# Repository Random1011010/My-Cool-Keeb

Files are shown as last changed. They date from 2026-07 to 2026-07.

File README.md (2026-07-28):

# My-Cool-Keeb
# Name: Morning Star

**Morning Star** is a custom 81-key mechanical keyboard powered by the **Hack Club Orpheus Pico** (RP2040). Built with dual rotary encoders, ultra-quiet linear switches, and a custom 2-layer PCB inside a 3D-printed enclosure, it delivers a high-functionality, low-noise typing experience.

Screenshot 2026-07-28 at 3 13 28 PM

---

## 🛠️ Project Writeup

### What I Built
Morning Star is a custom-designed, 81-key mechanical keyboard featuring a dedicated function row, arrow cluster, and dual EC11 rotary encoders. 

* **Microcontroller**: Powered by the Hack Club Orpheus Pico (RP2040).
* **Sound Profile**: Engineered for silent operation using Outemu Silent White linear switches, blank MOA profile PBT keycaps, and pre-clipped Chosfox V3 plate-mount stabilizers.
* **PCB & Hardware**: Custom 2-layer PCB designed, housed in a 3D-printed enclosure held together with M3 brass heat-set inserts and stainless steel hex socket screws.

---

### Why I Built It
Standard off-the-shelf mechanical keyboards are often either too noisy for shared environments or lack the physical control density needed for media editing, live sound workflows, and rapid navigation. 

I wanted to design a custom board from scratch that solved these problems:
1. **Dual Encoder Control**: Placing two tactile knobs directly on the layout gives instant physical control over volume, timeline scrubbing, and macro adjustments without leaving the home row.
2. **Silent Treatment**: By choosing silent white linear switches and plate-mounted stabilizers with pre-clipped stems, I wanted to eliminate rattle and any noise (I study at night so I would get in trouble if it was loud).

---

### What I Learned
Building Morning Star involved learning hardware production, PCB fabrication constraints, and firmware matrix logic:

* **PCB Manufacturing & Cost Optimization**: I learned how small design decisions directly impact manufacturing price. By selecting "Tented" via covering, I eliminated extra processing surcharges on JLCPCB while keeping standard matrix routing intact.
* **Hardware Sourcing & Budgeting**: Balancing component lead times and shipping fees taught me how to structure a realistic Bill of Materials across multiple suppliers (AliExpress, Amazon, JLCPCB) while staying strictly within budget limits.
* **Mechanical Design & Fasteners**: I learned why direct-threading screws into 3D-printed plastic leads to stripped threads over time, and how using a soldering iron to melt brass heat-set inserts into internal bosses provides strong, long-lasting metal threads for continuous teardowns.
* **Matrix Logic & Firmware**: I gained experience configuring diode-isolated key matrices (1N4148 diodes) to ensure full N-Key Rollover (NKRO) without ghosting, as well as mapping quadrature encoder signals to GPIO pins on the RP2040.

---

## 📋 Bill of Materials (BOM)

| Part Description | Qty | Unit Cost (USD) | Total Cost (USD) | Source / Link |
| :--- | :---: | :---: | :---: | :--- |
| **Orpheus Pico Microcontroller** | 1 | $0.00 | $0.00 | [Hack Club GitHub](https://github.com/hackclub/orpheus-pico) |
| **Outemu Silent White Linear Switches** (90 pcs) | 90 | $0.27 | $23.90 | [AliExpress](https://www.aliexpress.com/item/1005002378701948.html) |
| **132-Key White Blank MOA Profile Keycaps** | 1 | $20.96 | $20.96 | [AliExpress](https://www.aliexpress.com/) |
| **1N4148 Signal Diodes** (100-pack) | 100 | $0.016 | $1.64 | [AliExpress](https://www.aliexpress.com/item/1005002339916163.html) |
| **EC11 20mm Rotary Encoders** (2-pack) | 1 | $3.50 | $3.50 | [AliExpress](https://www.aliexpress.com/) |
| **M3 x 20mm Stainless Steel Screws** (100-pack) | 100 | $0.052 | $5.22 | [AliExpress](https://www.aliexpress.com/) |
| **HANGLIFE M3 Brass Heat-Set Inserts** (100-pack) | 100 | $0.057 | $5.66 | [Amazon Canada](https://www.amazon.ca/) |
| **Chosfox V3 Plate Mount Stabilizers Kit** | 1 | $8.57 | $8.57 | [AliExpress](https://www.aliexpress.com/item/1005007299976098.html) |
| **Custom 2-Layer PCB Fabrication** (5 pcs total) | 1 | $58.85 | $58.85 | [JLCPCB](https://jlcpcb.com/) |
| **Total Estimated Cost** | | | **~$128.30 USD** | |

---

## 🛠️ Hardware Specifications

* **MCU**: Hack Club Orpheus Pico (RP2040)
* **Matrix Architecture**
* **Encoders**: 2x EC11 5-pin encoders connected to dedicated GPIO channels.
* **Enclosure Fasteners**: M3 x D5 x L4 mm brass heat-set inserts with M3 x 20mm.
* **Stabilizers**: Chosfox V3 plate-mount stabilizers for keycaps ≥ 2u.

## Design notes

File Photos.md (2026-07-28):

### Photos ###
Screenshot 2026-07-15 at 4 56 42 PM








Screenshot 2026-07-28 at 3 13 28 PM

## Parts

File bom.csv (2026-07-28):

Item | Description | Quantity | Unit Price (USD) | Total Price (USD) | Purchase Link
Orpheus Pico Microcontroller | Hack Club RP2040 Board (Orpheus Pico) | 1 | 0.00 | 0.00 | https://github.com/hackclub/orpheus-pico
Mechanical Switches | Outemu Silent White Linear Switches (90 pcs) | 90 | 0.27 | 23.90 | https://www.aliexpress.com/item/1005002378701948.html
Keycap Set | 132 Keys White Blank MOA Profile PBT Keycaps | 1 | 20.96 | 20.96 | https://www.aliexpress.com/item/1005009872636789.html?mp=1
1N4148 Diodes | 100pcs 1N4148 In-line Switching Diodes | 100 | 0.016 | 1.64 | https://www.aliexpress.com/item/1005002339916163.html
EC11 Rotary Encoders | EC11 20mm D-Shaft Rotary Encoder | 2 | 1.75 | 3.50 | https://www.aliexpress.com/item/1005008790852587.html?mp=1
PCB Mount Stabilizers | 2x Stabilizers (1x Spacebar 6.25u / 1x Left Shift 2u) | 2 | 1.82 | 3.65 | https://www.aliexpress.com/item/1005007299976098.html
M3 screws | M3 x 20mm Machine Screws | 1 | 5.22 | 5.22 | https://www.aliexpress.com/item/32794842281.html?mp=1
Heat-Set Inserts | HANGLIFE 100pcs M3 x D5 x L4 Brass Heat-Set Threaded Inserts | 100 | 0.057 | 5.66 | https://www.amazon.ca/gp/product/B0CS6VZYL8/ref=ewc_pr_img_1?smid=A2SU9MLZ0N1BK2&th=1
Custom PCB Fabrication | JLCPCB 2-Layer Custom PCB (5 pcs incl. shipping & duties) | 1 | 58.85 | 58.85 | https://jlcpcb.com/
TOTAL |  |  |  |  | $128.30

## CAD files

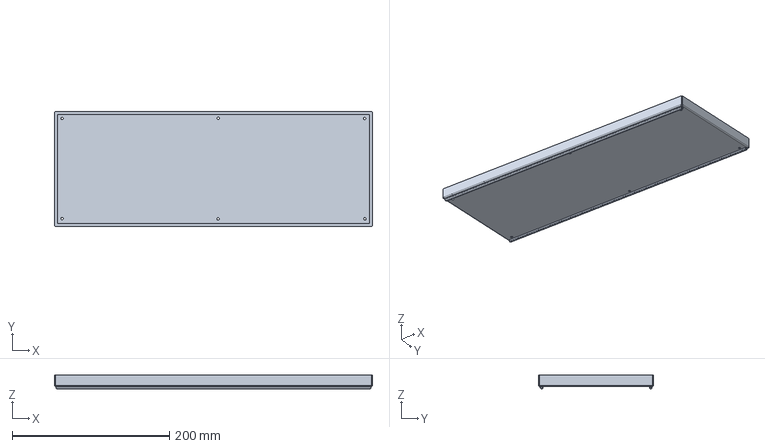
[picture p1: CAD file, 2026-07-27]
Case Files/Bottom Plate.step
404.1 x 145.9 x 17.5 mm

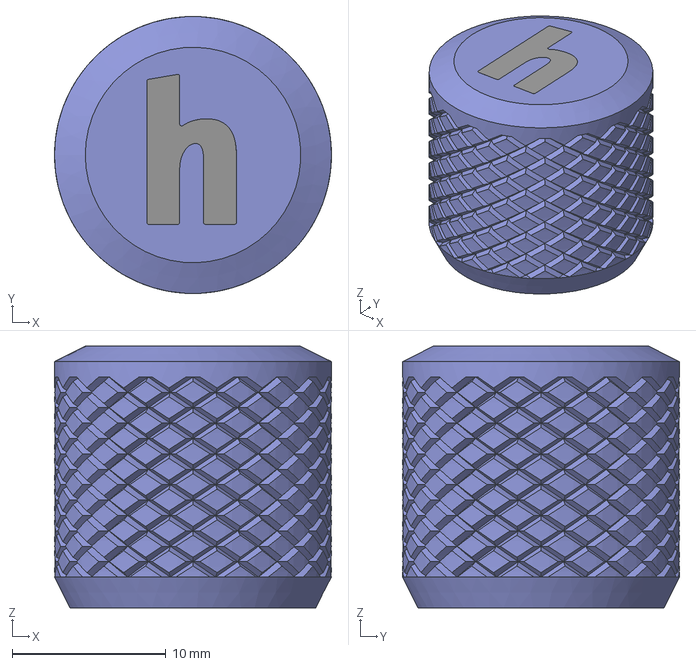
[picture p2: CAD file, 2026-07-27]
Case Files/Knob 1.step
18.0 x 18.0 x 17.0 mm

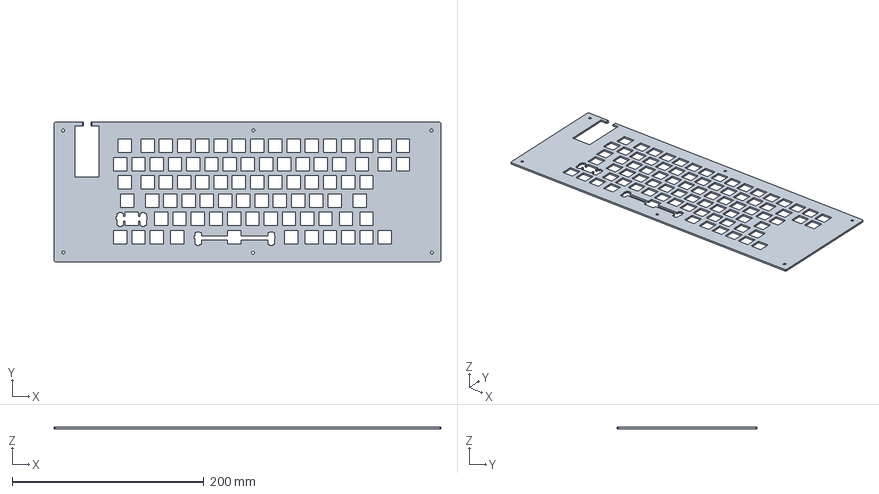
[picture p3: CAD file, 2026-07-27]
Case Files/Mid Plate.step
404.1 x 145.9 x 2.00 mm

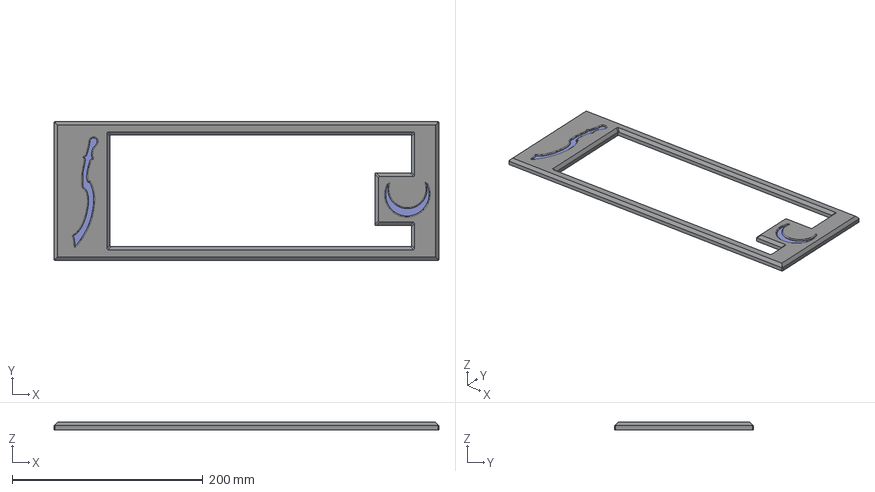
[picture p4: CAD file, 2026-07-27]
Case Files/Top Plate.step
404.1 x 145.9 x 8.00 mm

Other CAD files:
Case Files/Knob 2.step

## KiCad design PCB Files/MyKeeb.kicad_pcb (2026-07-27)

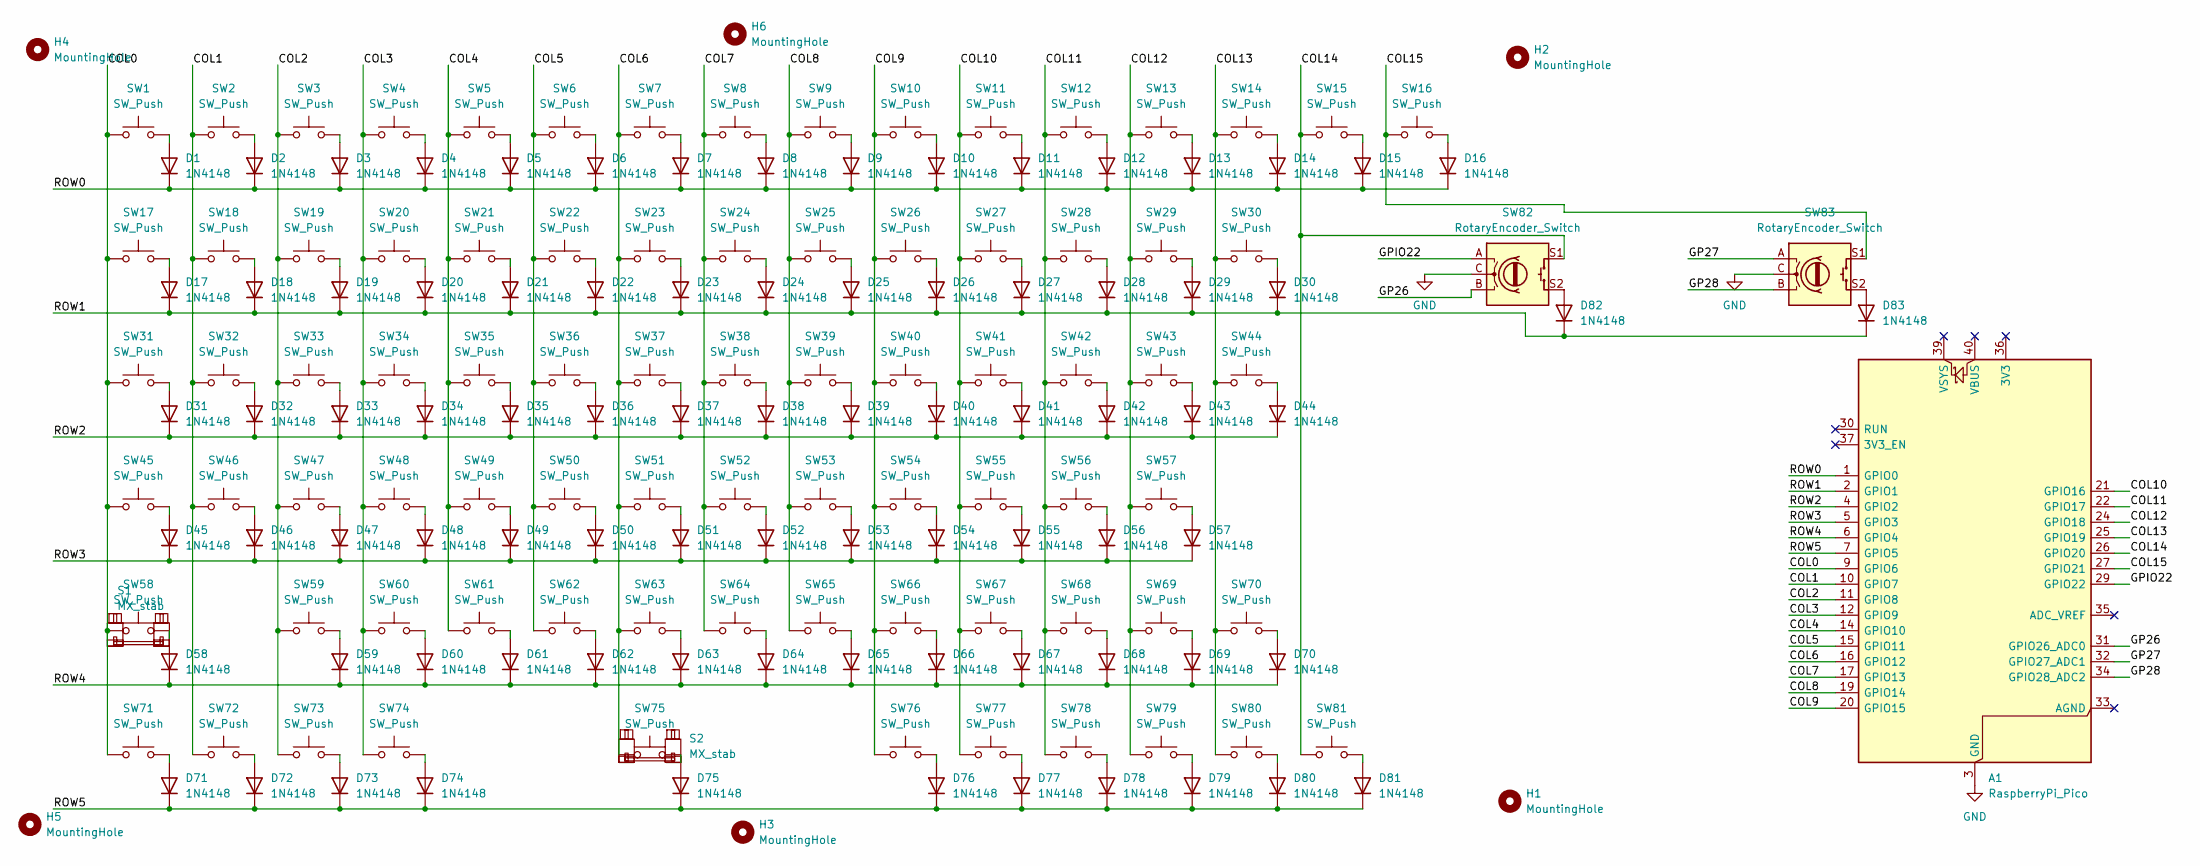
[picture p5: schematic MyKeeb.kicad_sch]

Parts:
A1: RaspberryPi_Pico; RaspberryPi_Pico_Common_THT
D1, D2, D3, D4, D5, D6, D7, D8, D9, D10, D11, D12, D13, D14, D15, D16, D17, D18, D19, D20, D21, D22, D23, D24, D25, D26, D27, D28, D29, D30, D31, D32, D33, D34, D35, D36, D37, D38, D39, D40, D41, D42, D43, D44, D45, D46, D47, D48, D49, D50, D51, D52, D53, D54, D55, D56, D57, D58, D59, D60, D61, D62, D63, D64, D65, D66, D67, D68, D69, D70, D71, D72, D73, D74, D75, D76, D77, D78, D79, D80, D81, D82, D83: 1N4148; D_DO-35_SOD27_P7.62mm_Horizontal
H1, H2, H3, H4, H5, H6: MountingHole; MountingHole_3.2mm_M3
S1: MX_stab; STAB_MX_P_2.25u
S2: MX_stab; STAB_MX_P_5u
SW1, SW30, SW31: SW_Push; SW_MX_1.5u
SW2, SW3, SW4, SW5, SW6, SW7, SW8, SW9, SW10, SW11, SW12, SW13, SW14, SW15, SW16, SW17, SW18, SW19, SW20, SW21, SW22, SW23, SW24, SW25, SW26, SW27, SW28, SW29, SW32, SW33, SW34, SW35, SW36, SW37, SW38, SW39, SW40, SW41, SW42, SW43, SW44, SW46, SW47, SW48, SW49, SW50, SW51, SW52, SW53, SW54, SW55, SW56, SW58, SW59, SW60, SW61, SW62, SW63, SW64, SW65, SW66, SW67, SW68, SW70, SW71, SW72, SW73, SW75, SW77, SW78, SW79, SW80, SW81: SW_Push; SW_MX_1u
SW45, SW57: SW_Push; SW_MX_1.75u
SW69, SW74, SW76: SW_Push; SW_MX_1.25u
SW82, SW83: RotaryEncoder_Switch; ROT_Alps_EC11E-Switch

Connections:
/COL0: A1.9 (GPIO6), SW1.1, SW17.1, SW31.1, SW45.1, SW58.1, SW71.1
/COL1: A1.10 (GPIO7), SW2.1, SW18.1, SW32.1, SW46.1, SW72.1
/COL2: A1.11 (GPIO8), SW3.1, SW19.1, SW33.1, SW47.1, SW59.1, SW73.1
/COL3: A1.12 (GPIO9), SW4.1, SW20.1, SW34.1, SW48.1, SW60.1, SW74.1
/COL4: A1.14 (GPIO10), SW5.1, SW21.1, SW35.1, SW49.1, SW61.1
/COL5: A1.15 (GPIO11), SW6.1, SW22.1, SW36.1, SW50.1, SW62.1
/COL6: A1.16 (GPIO12), SW7.1, SW23.1, SW37.1, SW51.1, SW63.1, SW75.1
/COL7: A1.17 (GPIO13), SW8.1, SW24.1, SW38.1, SW52.1, SW64.1
/COL8: A1.19 (GPIO14), SW9.1, SW25.1, SW39.1, SW53.1, SW65.1
/COL9: A1.20 (GPIO15), SW10.1, SW26.1, SW40.1, SW54.1, SW66.1, SW76.1
/COL10: A1.21 (GPIO16), SW11.1, SW27.1, SW41.1, SW55.1, SW67.1, SW77.1
/COL11: A1.22 (GPIO17), SW12.1, SW28.1, SW42.1, SW56.1, SW68.1, SW78.1
/COL12: A1.24 (GPIO18), SW13.1, SW29.1, SW43.1, SW57.1, SW69.1, SW79.1
/COL13: A1.25 (GPIO19), SW14.1, SW30.1, SW44.1, SW70.1, SW80.1
/COL14: A1.26 (GPIO20), SW15.1, SW81.1, SW82.S1
/COL15: A1.27 (GPIO21), SW16.1, SW83.S1
/GP26: A1.31 (GPIO26_ADC0), SW82.B
/GP27: A1.32 (GPIO27_ADC1), SW83.A
/GP28: A1.34 (GPIO28_ADC2), SW83.B
/GPIO22: A1.29 (GPIO22), SW82.A
/ROW0: A1.1 (GPIO0), D1.1 (K), D2.1 (K), D3.1 (K), D4.1 (K), D5.1 (K), D6.1 (K), D7.1 (K), D8.1 (K), D9.1 (K), D10.1 (K), D11.1 (K), D12.1 (K), D13.1 (K), D14.1 (K), D15.1 (K), D16.1 (K)
/ROW1: A1.2 (GPIO1), D17.1 (K), D18.1 (K), D19.1 (K), D20.1 (K), D21.1 (K), D22.1 (K), D23.1 (K), D24.1 (K), D25.1 (K), D26.1 (K), D27.1 (K), D28.1 (K), D29.1 (K), D30.1 (K), D82.1 (K), D83.1 (K)
/ROW2: A1.4 (GPIO2), D31.1 (K), D32.1 (K), D33.1 (K), D34.1 (K), D35.1 (K), D36.1 (K), D37.1 (K), D38.1 (K), D39.1 (K), D40.1 (K), D41.1 (K), D42.1 (K), D43.1 (K), D44.1 (K)
/ROW3: A1.5 (GPIO3), D45.1 (K), D46.1 (K), D47.1 (K), D48.1 (K), D49.1 (K), D50.1 (K), D51.1 (K), D52.1 (K), D53.1 (K), D54.1 (K), D55.1 (K), D56.1 (K), D57.1 (K)
/ROW4: A1.6 (GPIO4), D58.1 (K), D59.1 (K), D60.1 (K), D61.1 (K), D62.1 (K), D63.1 (K), D64.1 (K), D65.1 (K), D66.1 (K), D67.1 (K), D68.1 (K), D69.1 (K), D70.1 (K)
/ROW5: A1.7 (GPIO5), D71.1 (K), D72.1 (K), D73.1 (K), D74.1 (K), D75.1 (K), D76.1 (K), D77.1 (K), D78.1 (K), D79.1 (K), D80.1 (K), D81.1 (K)
GND: A1.3 (GND), A1.8 (GND), A1.13 (GND), A1.18 (GND), A1.23 (GND), A1.28 (GND), A1.38 (GND), SW82.C, SW83.C
unnamed: D1.2 (A), SW1.2
unnamed: D2.2 (A), SW2.2
unnamed: D3.2 (A), SW3.2
unnamed: D4.2 (A), SW4.2
unnamed: D5.2 (A), SW5.2
unnamed: D6.2 (A), SW6.2
unnamed: D7.2 (A), SW7.2
unnamed: D8.2 (A), SW8.2
unnamed: D9.2 (A), SW9.2
unnamed: D10.2 (A), SW10.2
unnamed: D11.2 (A), SW11.2
unnamed: D12.2 (A), SW12.2
unnamed: D13.2 (A), SW13.2
unnamed: D14.2 (A), SW14.2
unnamed: D15.2 (A), SW15.2
unnamed: D16.2 (A), SW16.2
unnamed: D17.2 (A), SW17.2
unnamed: D18.2 (A), SW18.2
unnamed: D19.2 (A), SW19.2
unnamed: D20.2 (A), SW20.2
unnamed: D21.2 (A), SW21.2
unnamed: D22.2 (A), SW22.2
unnamed: D23.2 (A), SW23.2
unnamed: D24.2 (A), SW24.2
unnamed: D25.2 (A), SW25.2
unnamed: D26.2 (A), SW26.2
unnamed: D27.2 (A), SW27.2
unnamed: D28.2 (A), SW28.2
unnamed: D29.2 (A), SW29.2
unnamed: D30.2 (A), SW30.2
unnamed: D31.2 (A), SW31.2
unnamed: D32.2 (A), SW32.2
unnamed: D33.2 (A), SW33.2
unnamed: D34.2 (A), SW34.2
unnamed: D35.2 (A), SW35.2
unnamed: D36.2 (A), SW36.2
unnamed: D37.2 (A), SW37.2
unnamed: D38.2 (A), SW38.2
unnamed: D39.2 (A), SW39.2
unnamed: D40.2 (A), SW40.2
unnamed: D41.2 (A), SW41.2
unnamed: D42.2 (A), SW42.2
unnamed: D43.2 (A), SW43.2
unnamed: D44.2 (A), SW44.2
unnamed: D45.2 (A), SW45.2
unnamed: D46.2 (A), SW46.2
unnamed: D47.2 (A), SW47.2
unnamed: D48.2 (A), SW48.2
unnamed: D49.2 (A), SW49.2
unnamed: D50.2 (A), SW50.2
unnamed: D51.2 (A), SW51.2
unnamed: D52.2 (A), SW52.2
unnamed: D53.2 (A), SW53.2
unnamed: D54.2 (A), SW54.2
unnamed: D55.2 (A), SW55.2
unnamed: D56.2 (A), SW56.2
unnamed: D57.2 (A), SW57.2
unnamed: D58.2 (A), SW58.2
unnamed: D59.2 (A), SW59.2
unnamed: D60.2 (A), SW60.2
unnamed: D61.2 (A), SW61.2
unnamed: D62.2 (A), SW62.2
unnamed: D63.2 (A), SW63.2
unnamed: D64.2 (A), SW64.2
unnamed: D65.2 (A), SW65.2
unnamed: D66.2 (A), SW66.2
unnamed: D67.2 (A), SW67.2
unnamed: D68.2 (A), SW68.2
unnamed: D69.2 (A), SW69.2
unnamed: D70.2 (A), SW70.2
unnamed: D71.2 (A), SW71.2
unnamed: D72.2 (A), SW72.2
unnamed: D73.2 (A), SW73.2
unnamed: D74.2 (A), SW74.2
unnamed: D75.2 (A), SW75.2
unnamed: D76.2 (A), SW76.2
unnamed: D77.2 (A), SW77.2
unnamed: D78.2 (A), SW78.2
unnamed: D79.2 (A), SW79.2
unnamed: D80.2 (A), SW80.2
unnamed: D81.2 (A), SW81.2
unnamed: D82.2 (A), SW82.S2
unnamed: D83.2 (A), SW83.S2

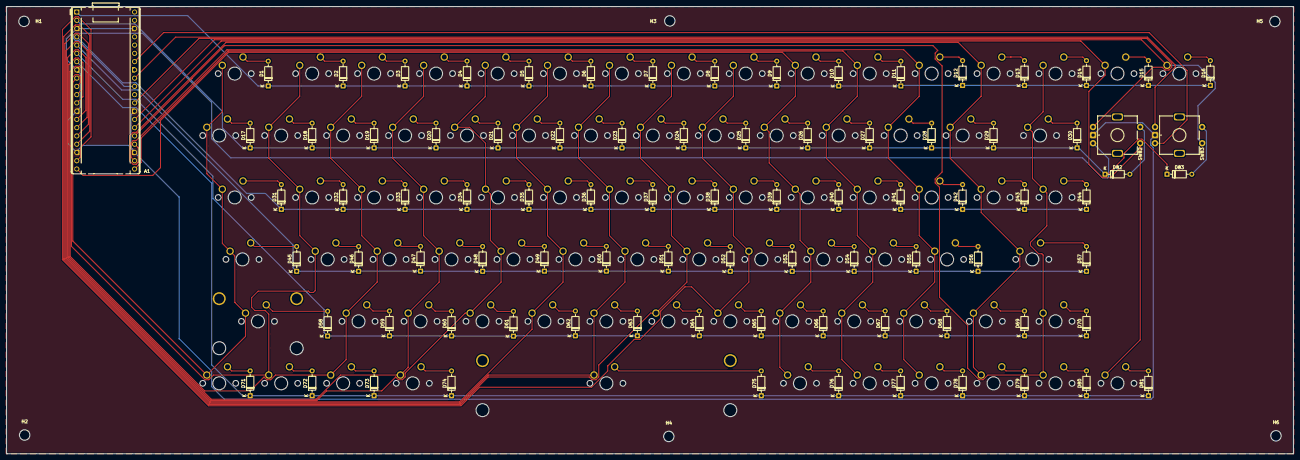
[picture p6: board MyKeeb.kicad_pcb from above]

Board: 2 copper layers, 395.7 x 137.5 mm, 175 parts (0 on the bottom side), 110 nets.

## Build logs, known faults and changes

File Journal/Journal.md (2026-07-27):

# This is my journal!! (total hours worked = 17😎🔥)

### I will be posting the journal decriptions, images of my work, and the hour(s) spent per journal log 
### (Date will be mm/dd/yyyy)

## Journal log 1 (+1h) (07/15/2026)
I just started with the schematic! I managed to get the rough layout of where the keys will be along with where the rotary encoders and the stablizers need to be. I also added all the diodes with 

Some problems I am facing right now would be that i am not sure how to place the switches properly on the schematic without something looking off and bothering me to the ends the earth💀

Somethings I plan to tackle next. I plan to tackle adding all the net labels, The actual pico cause I lowkey forgot to place that in 😅, and making sure the parts line up in the layout that I want them to.

Screenshot 2026-07-15 at 4 56 42 PM

## Journal log 2 (+2h) (07/17/2026)
It took so long to fix everything up on the schematic, but i finally added all the parts needed such as the pico and well that is kinda all I added but wiring it took more time then I thought because I was not able to figure out how to add bluetooth so I had to scrap that idea

Some problems I can imagine I am going to face is going to be adding the switch 3d model into the schematic so that I don't have to manually add that in when I import the pcb into fustion 360

Somethings I plan to tackle next, I plan to try and add the 3d model to the schematic like I said before, but also I want to have the spacing for all the switches on the pcb be proper for the pieces that are more then 1u

Screenshot 2026-07-17 at 11 31 54 PM

## Journal log 3 (+2h) (07/18/2026)
I took way to long to get the footprints correct so that they would have the correct u size, but I got that done, plus most of major wiring done one the PCB

Some problems I faced were the footprints just NOT lining up properly and having to shimmy like 100 times till it works, another problem I am going to imagine its going to be hard is again the 3d models of the switches, and a new problem I can think of is finding a 5u space bar, and a 2.25 shift key (Like the caps)

I plan to next finish up the PCB and get started with the Case! I have a bunch of cool ideas for details I want to add on the keyboard, hopefully I don't forget them.💀😅

Screenshot 2026-07-18 at 4 03 59 AM

## Journal log 4 (+1h) (07/18/2026)
I finally finished routing all the wires on the PCB, I am finally ready to export the PCB and start with the case!
Screenshot 2026-07-18 at 1 34 32 PM

## Journal log 5 (+2h) (07/18/2026)
It tool so long to make the keyboard plate and I am still not done😭🙏, it turns out that I have to now find a 5u stabelizer for the 3d model and also make the cut out on the spacebar section of the plate.
Screenshot 2026-07-18 at 5 14 19 PM

## Journal log 6 (+1h) (07/19/2026)
I am really struggling to make the case, but I think I am on the right track for the case, I feel like the top cover will kinda help everything click (or so I hope)

Screenshot 2026-07-19 at 1 33 11 AM

## Journal log 7 (+2h) (07/19/2026)
It is taking so long to make the case, but I am almost done the case, now the main problem is doing to be making sure the mounting holes are correct, putting the correct colors on the keycaps, putting my own details on the case, making & putting the encoder caps, making a 5u spacebar model, and just putting all the finalizing touches.Screenshot 2026-07-19 at 6 49 01 PM

## Journal log 8 (+4h) (07/26/2026)
This was the longest I worked on the keyboard and even though it doesn't look like much of a differnce in the photos, I would say that today was when i really finished off the keyboard because now all I have left is the actually firmware, and i hope that will be less difficult.
Why it took so long. It took so long for just a bit of change is the fact that I had to make my own spacebar, had to fix any clearence issues, gave the whole keyboard color, make the port area look better, added my own custom designs into the top plate of the keyboard to make it my own, added heatset inserts, added the screws, and fixed any smaller things I might have missed in this up
Screenshot 2026-07-27 at 2 04 12 AM

## Journal log 9 (+2h) (07/27/2026)
It surprisingly didn't take that long to make the firmware to fit my hardware with the encoders, I just need to figure out how I should put the firmware files into this repo because for the firmware you had to make the code in another repo, but other then that I just need to add all the files that I have into their respective folders in the repo and make sure everything is correct before sending it in

Screenshot 2026-07-27 at 3 06 22 PM

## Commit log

2026-06-29 Created PCB Files
2026-06-29 Create Case Files
2026-07-15 Add journal log 1 with initial schematic details
    Added journal entry detailing work on schematic layout and future plans.
2026-07-18 Add Journal log 2 with schematic updates
    Documented progress on schematic updates and future plans.
2026-07-18 Add journal log 3 with PCB updates and plans
    Added journal log 3 detailing progress on PCB and challenges faced.
2026-07-18 Update journal hours and add new log entry
    Updated total hours worked in the journal and added a new journal log entry detailing progress on the PCB.
2026-07-19 Update journal hours and add new log entry
    Updated total hours worked in the journal header and added a new journal log with details about the case construction.
2026-07-19 Update journal hours and add new log entry
    Updated total hours worked in the journal and added a new journal log detailing progress on the case.
2026-07-27 Added PCB files
    [MyKeeb.kicad_pcb, MyKeeb.kicad_sch]
2026-07-27 Added Case Files
    [Bottom Plate.step, Knob 1.step, Knob 2.step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]
2026-07-27 Add BOM entries for components and pricing
    [BOM.csv]
2026-07-27 Modify BOM header to include tax information
    Updated the BOM to include 'Total Price (CAD)(Without Tax)' in the header.
    [BOM.csv]
2026-07-28 Modify bom.csv with new items and links
    Updated product links and added new items to the bill of materials.
    [bom.csv]
2026-07-28 Add Bill of Materials section to README
    Added a Bill of Materials (BOM) section to the README with detailed parts and costs for the keyboard project.
